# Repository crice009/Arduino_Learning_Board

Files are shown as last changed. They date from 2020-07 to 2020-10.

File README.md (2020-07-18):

# Arduino_Learning_Board
A set of resources to help with teaching and learning the skills of Arduino: coding, soldering, electronics, inputs and outputs. These include Arduino shield designs, BOM for ordering supplies, example sketches and a simple website for guiding structured learning/ play with these resources. 

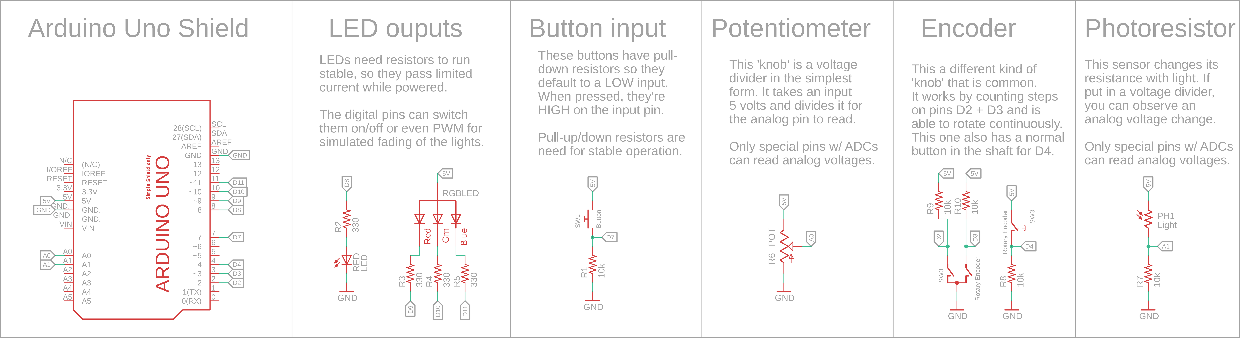
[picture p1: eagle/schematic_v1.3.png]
Schematic Image


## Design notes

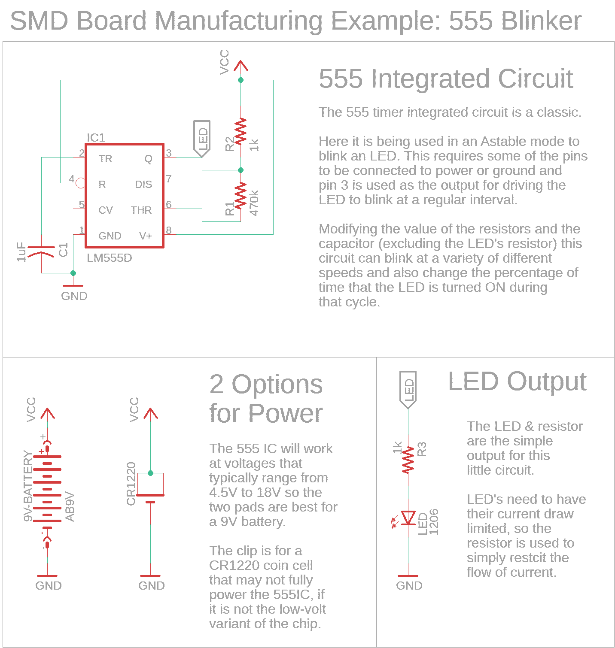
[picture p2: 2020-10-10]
eagle/schematic_555.png

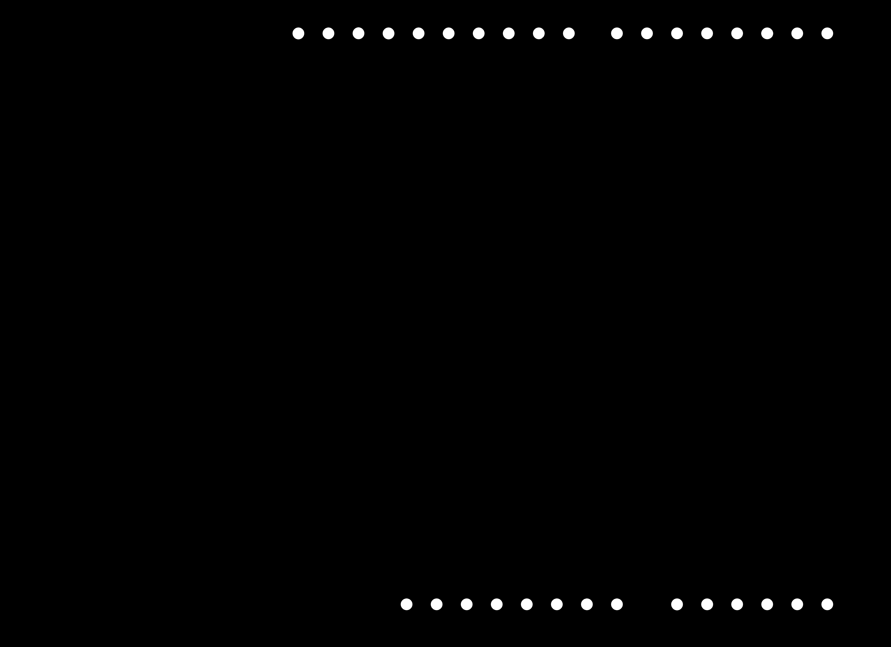
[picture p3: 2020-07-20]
eagle/single-sided_v2_holes.png

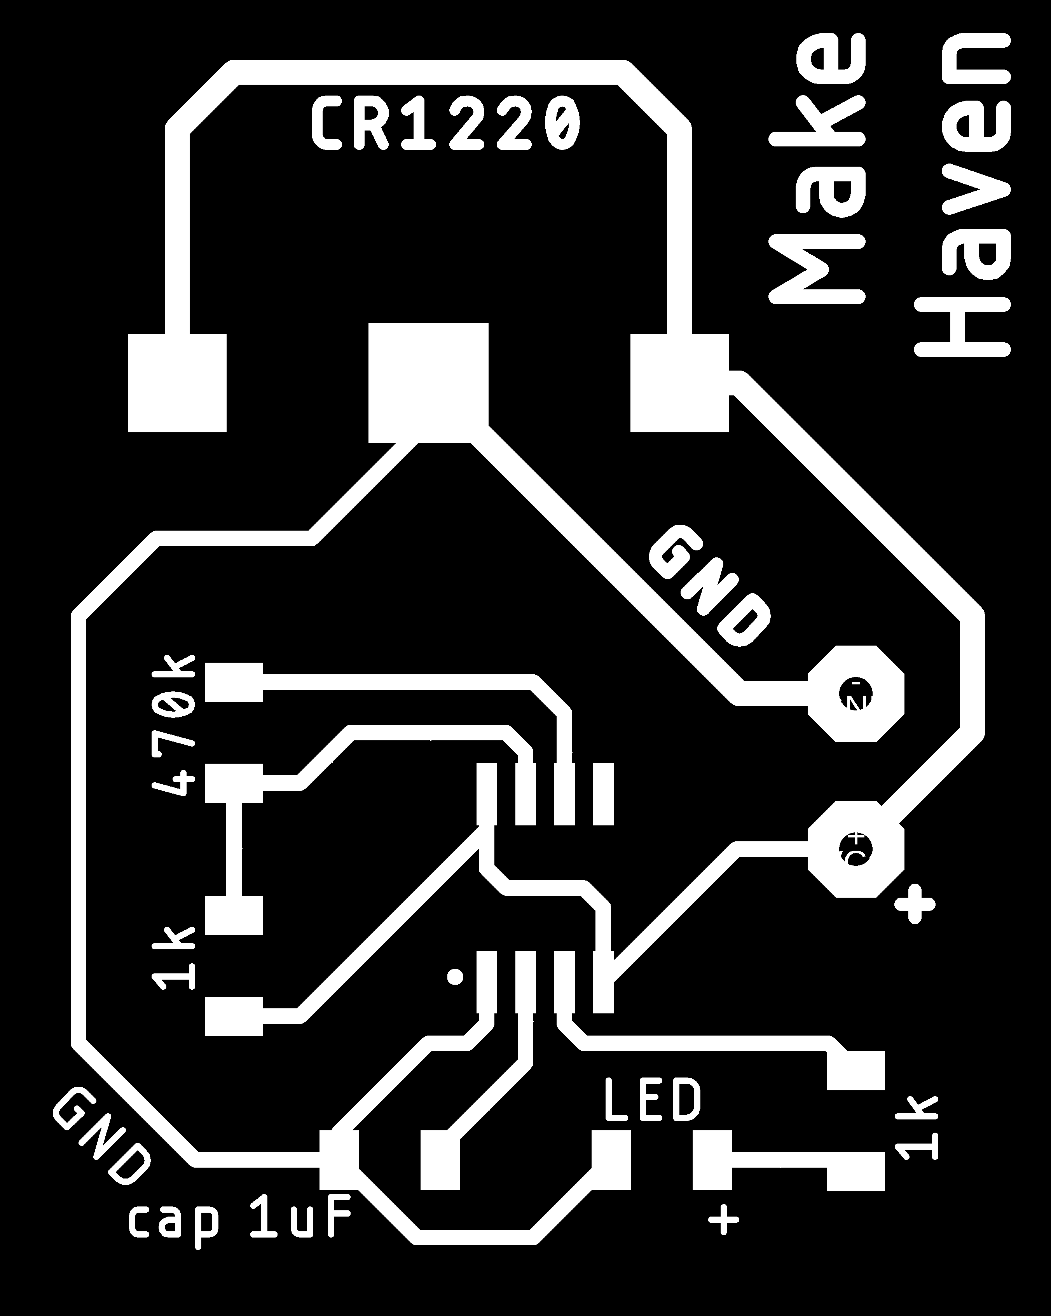
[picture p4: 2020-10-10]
eagle/555-blinker.png

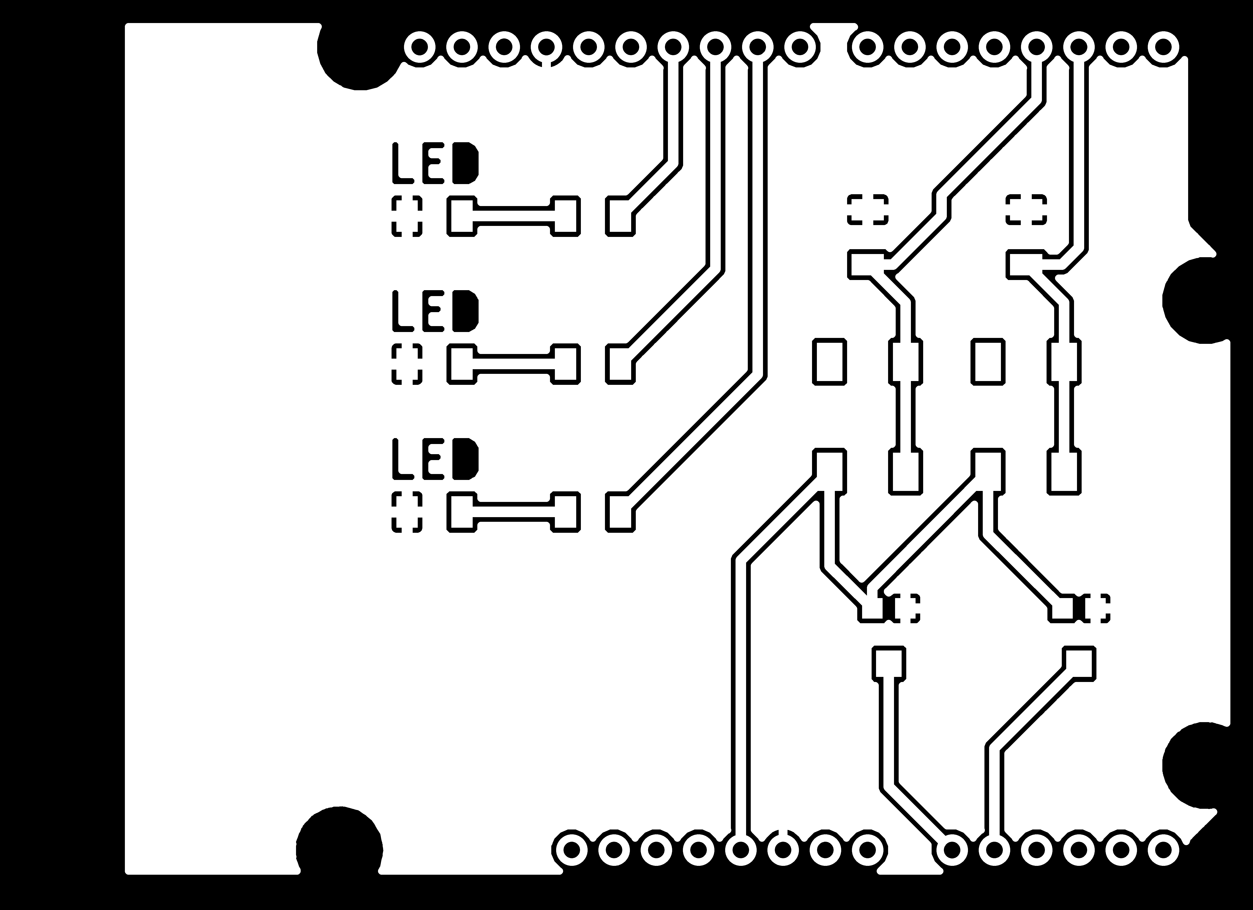
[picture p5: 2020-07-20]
eagle/single-sided_v2_traces_and_holes.png

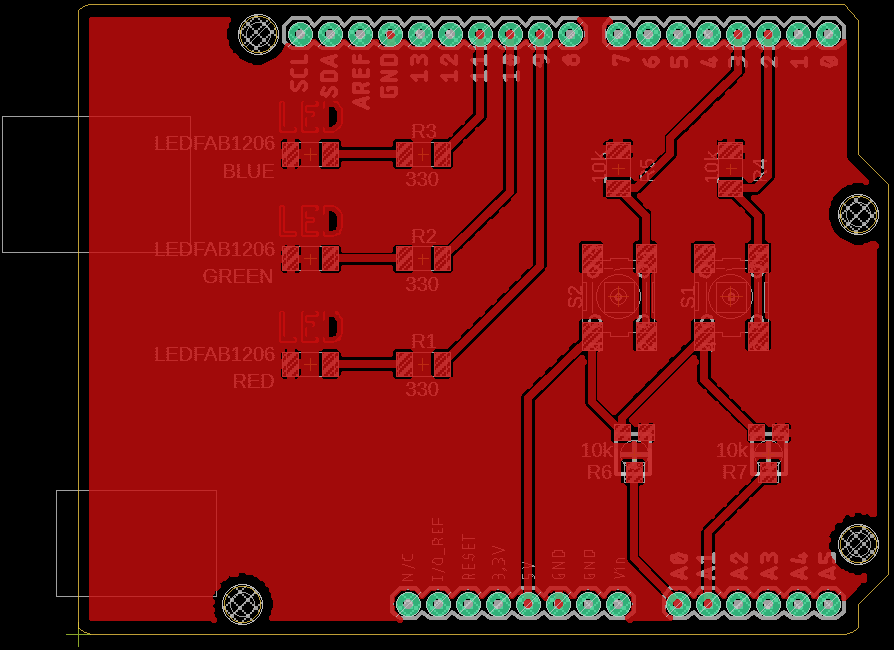
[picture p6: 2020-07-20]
eagle/single-sided_v2_color.png

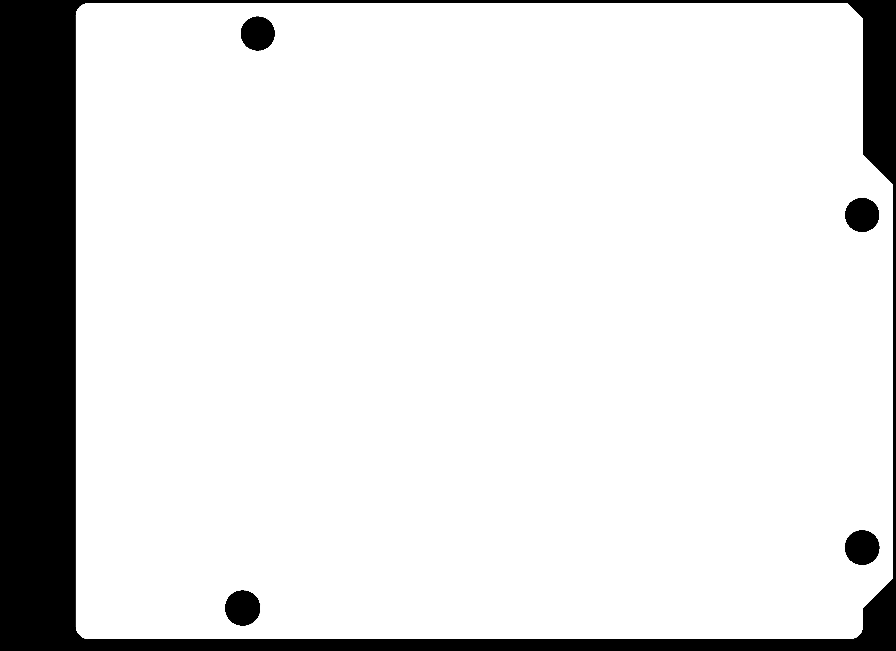
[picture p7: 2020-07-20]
eagle/single-sided_v2_cutout.png

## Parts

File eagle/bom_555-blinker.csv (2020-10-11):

Item | Quantity | individual cost | total cost | running total | Digikey
[8soic] 555-timer-IC (low-volts) | 1 | $0.88 | $0.88 | $0.88 | https://www.digikey.com/en/products/detail/texas-instruments/TLC555CDG4/1676492
[1206] 1 KOhm resistors | 2 | $0.10 | $0.20 | $1.08 | https://www.digikey.com/en/products/filter/chip-resistor-surface-mount/52
[1206] 470 KOhm resistors | 1 | $0.15 | $0.15 | $1.23 | https://www.digikey.com/en/products/filter/chip-resistor-surface-mount/52
[1206] LED | 1 | $0.26 | $0.26 | $1.49 | https://www.digikey.com/en/products/filter/led-indication-discrete/105?s=N4IgTCBcDaIIxgAwDYAEAbApgExAXQF8g
[1206] 1uF Capacitor | 1 | $0.14 | $0.14 | $1.63 | https://www.digikey.com/en/products/filter/ceramic-capacitors/60
CR1220 battery clip | 1 | $0.62 | $0.62 | $2.25 | https://www.digikey.com/en/products/detail/keystone-electronics/2894/9921790

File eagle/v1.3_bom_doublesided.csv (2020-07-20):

Item | Quantity | individual cost | total cost | running total | Digikey
male headers (6 pins long ea.) | 5 | $0.12 | $0.60 | $0.60 | https://www.digikey.com/product-detail/en/metz-connect-usa-inc/PR20206VBNN/1849-PR20206VBNN-ND/12342874
330 Ohm resistors | 4 | $0.10 | $0.40 | $1.00 | https://www.digikey.com/products/en/resistors/through-hole-resistors/53?k=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
10 KOhm resistors | 5 | $0.10 | $0.50 | $1.50 | https://www.digikey.com/products/en/resistors/through-hole-resistors/53?k=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
Single LED | 1 | $0.15 | $0.15 | $1.65 | https://www.digikey.com/products/en/optoelectronics/led-indication-discrete/105?k=5mm+led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
RGB LED | 1 | $1.01 | $1.01 | $2.66 | https://www.digikey.com/products/en/optoelectronics/led-indication-discrete/105?k=RGB+LED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
Button | 1 | $0.42 | $0.42 | $3.08 | https://www.digikey.com/products/en/switches/tactile-switches/197?k=EVQ-PE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
Encoder | 1 | $3.48 | $3.48 | $6.56 | https://www.digikey.com/product-detail/en/cui-devices/ACZ11BR1E-20FD1-20C/102-1768-ND/1923363
Potentiometer | 1 | $2.48 | $2.48 | $9.04 | https://www.digikey.com/products/en/potentiometers-variable-resistors/trimmer-potentiometers/80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
Phototcell | 1 | $0.89 | $0.89 | $9.93 | https://www.digikey.com/products/en/sensors-transducers/optical-sensors-photo-detectors-cds-cells/540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
board | 1 | $0.40 | $0.40 | $10.33 | Fab House

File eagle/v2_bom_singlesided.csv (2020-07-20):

Item | Quantity | individual cost | total cost | running total | Digikey
male headers (6 pins long ea.) | 5 | $0.12 | $0.60 | $0.60 | https://www.digikey.com/product-detail/en/metz-connect-usa-inc/PR20206VBNN/1849-PR20206VBNN-ND/12342874
330 Ohm SMD resistors | 3 | $0.10 | $0.30 | $0.90 | https://www.digikey.com/products/en/resistors/chip-resistor-surface-mount/52?k=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
10 KOhm SMD resistors | 2 | $0.10 | $0.20 | $1.10 | https://www.digikey.com/products/en/resistors/chip-resistor-surface-mount/52?k=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
Single SMD LED | 3 | $0.15 | $0.45 | $1.55 | https://www.digikey.com/products/en/optoelectronics/led-indication-discrete/105?k=1206+led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
button | 2 | $1.04 | $2.08 | $3.63 | https://www.digikey.com/product-detail/en/omron-electronics-inc-emc-div/B3SN-3112P/SW262CT-ND/60835
Potentiometer | 1 | $2.48 | $2.48 | $6.11 | https://www.digikey.com/products/en/potentiometers-variable-resistors/trimmer-potentiometers/80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
FR4 stock 6"x4" single sided | 0.5 | $7.34 | $3.67 | $9.78 | https://www.digikey.com/product-detail/en/mg-chemicals/506/473-1001-ND/559720

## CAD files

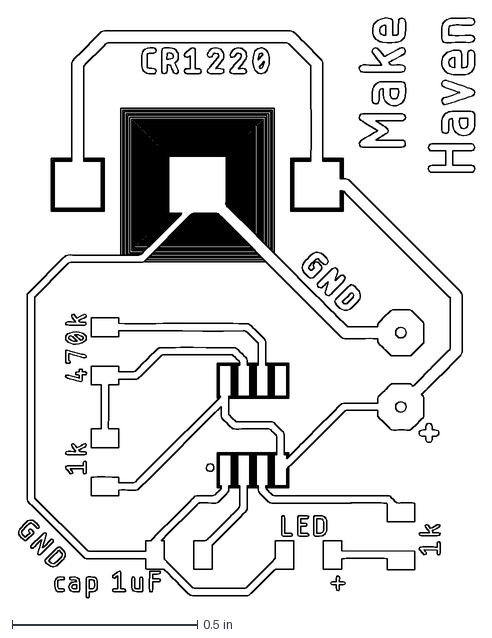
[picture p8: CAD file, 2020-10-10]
eagle/555-blinker.dxf
1.24 x 1.57 in

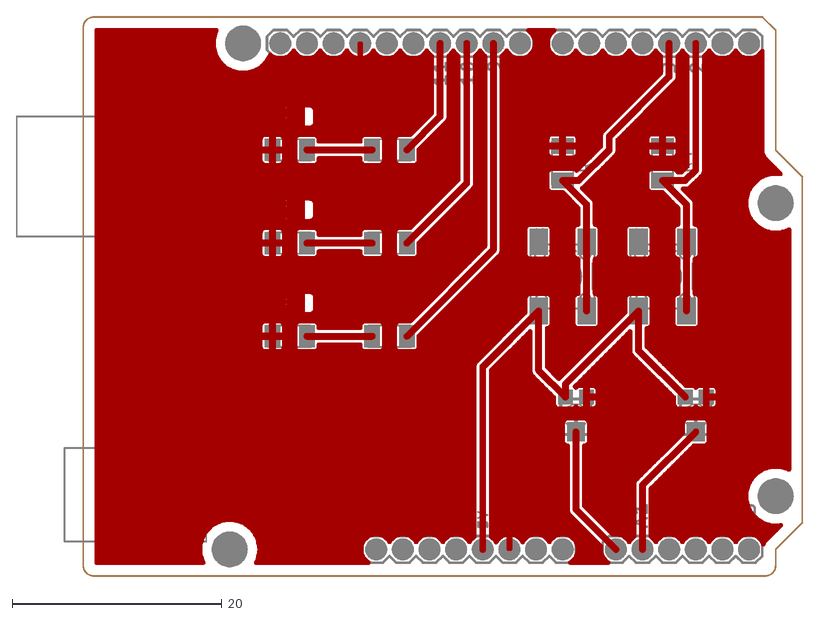
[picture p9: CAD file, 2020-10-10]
eagle/lb_single-sided_uno_v2.dxf
75.1 x 53.4

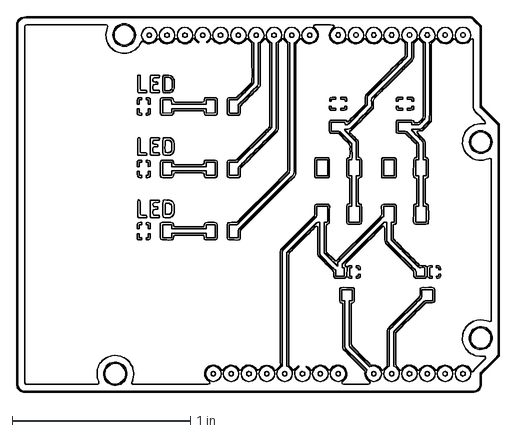
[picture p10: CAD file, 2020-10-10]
eagle/laserable-single-sided.dxf
2.71 x 2.11 in

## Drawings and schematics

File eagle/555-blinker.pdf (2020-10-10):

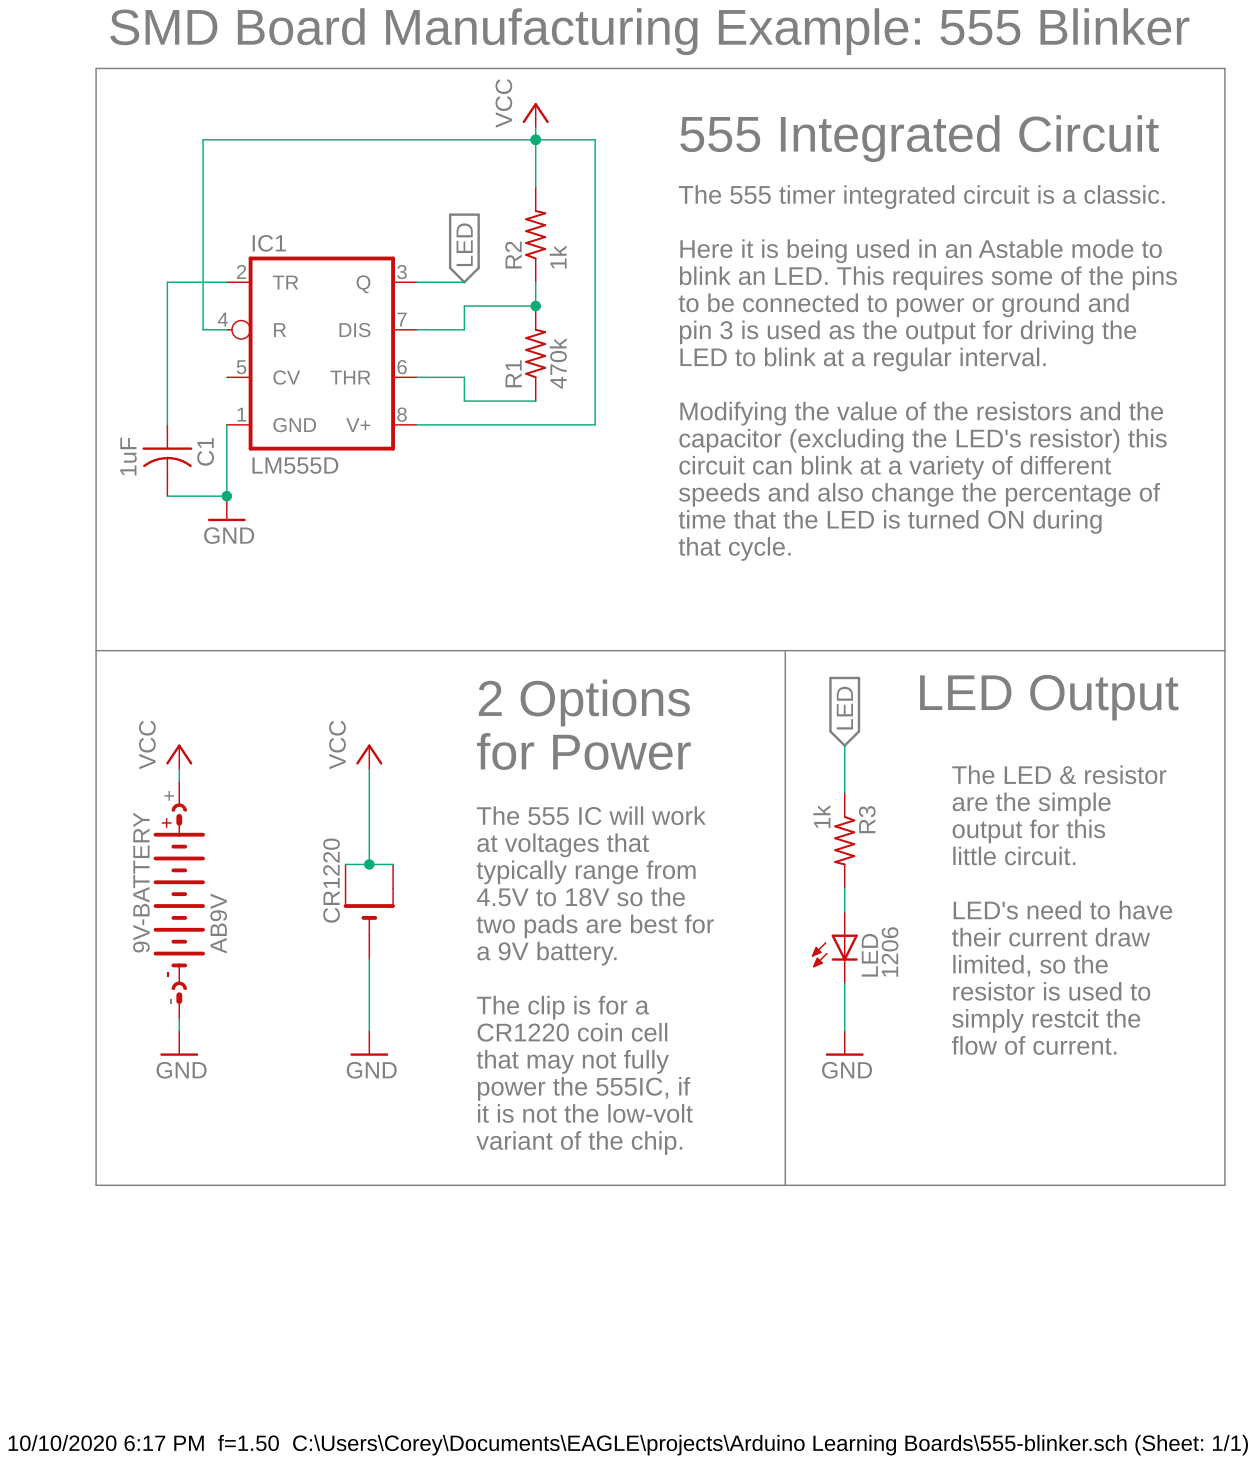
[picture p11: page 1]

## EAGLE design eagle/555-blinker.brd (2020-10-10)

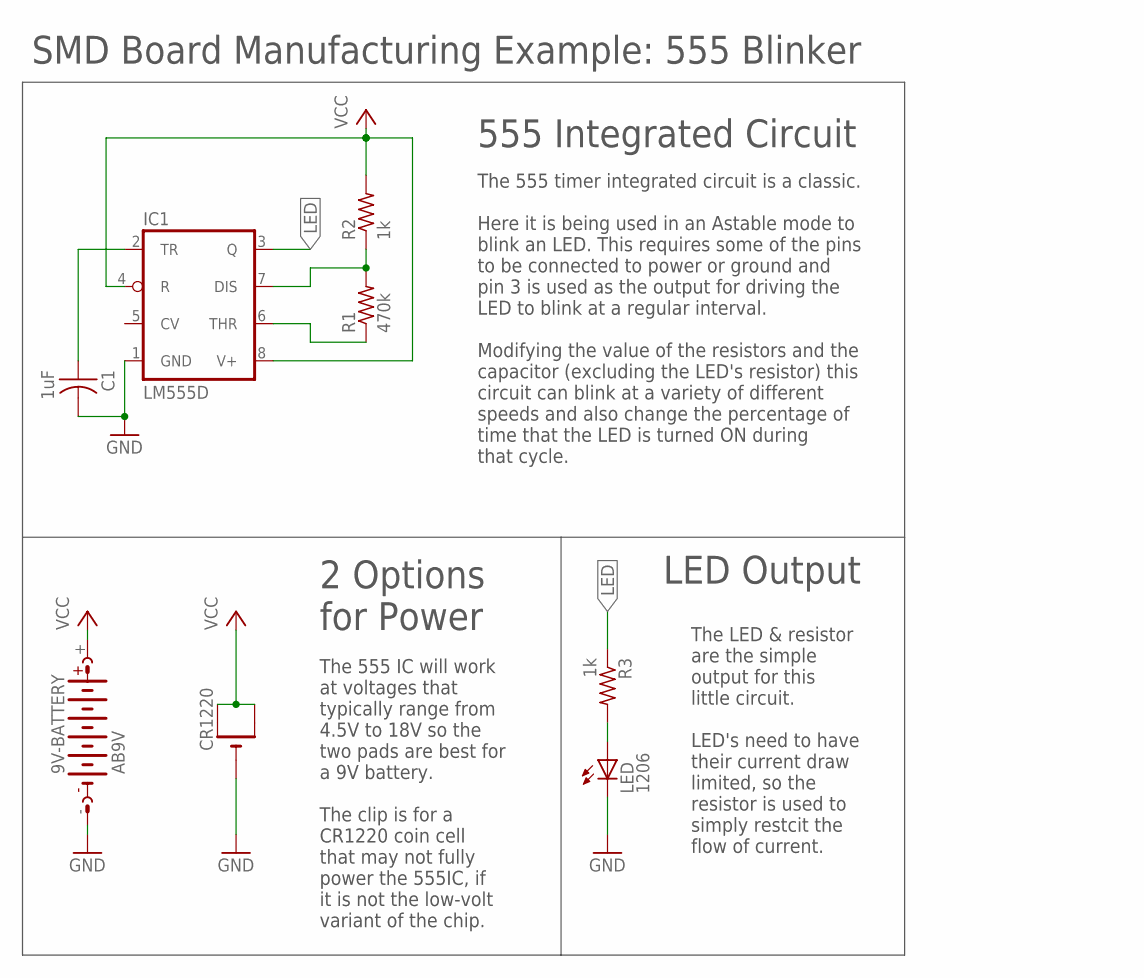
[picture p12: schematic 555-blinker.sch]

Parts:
9V-BATTERY: AB9V
C1: 1uF; C1206FAB
CR1220: CR1220SMT; CR1220-SMD
IC1: LM555D; SO08
LED: 1206; LED1206FAB
R1: 470k; R1206FAB
R2, R3: 1k; R1206FAB

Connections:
GND: 9V-BATTERY.-, C1.2, CR1220.-, IC1.1 (GND), LED.2 (C)
LED: IC1.3 (Q), R3.1
unnamed: IC1.7 (DIS), R1.2, R2.1
unnamed: IC1.6 (THR), R1.1
unnamed: C1.1, IC1.2 (TR)
unnamed: LED.1 (A), R3.2
VCC: 9V-BATTERY.+, CR1220.+$1 (+), CR1220.+$2 (+1), IC1.4 (R), IC1.8 (V+), R2.2

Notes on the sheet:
SMD Board Manufacturing Example: 555 Blinker
555 Integrated Circuit
2 Options for Power
LED Output
The 555 timer integrated circuit is a classic. Here it is being used in an Astable mode to blink an LED. This requires some of the pins to be connected to power or ground and pin 3 is used as the output for driving the LED to blink at a regular interval. Modifying the value of the resistors and the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
The 555 IC will work at voltages that typically range from 4.5V to 18V so the two pads are best for a 9V battery. The clip is for a CR1220 coin cell that may not fully power the 555IC, if it is not the low-volt variant of the chip.
The LED & resistor are the simple output for this little circuit. LED's need to have their current draw limited, so the resistor is used to simply restcit the flow of current.

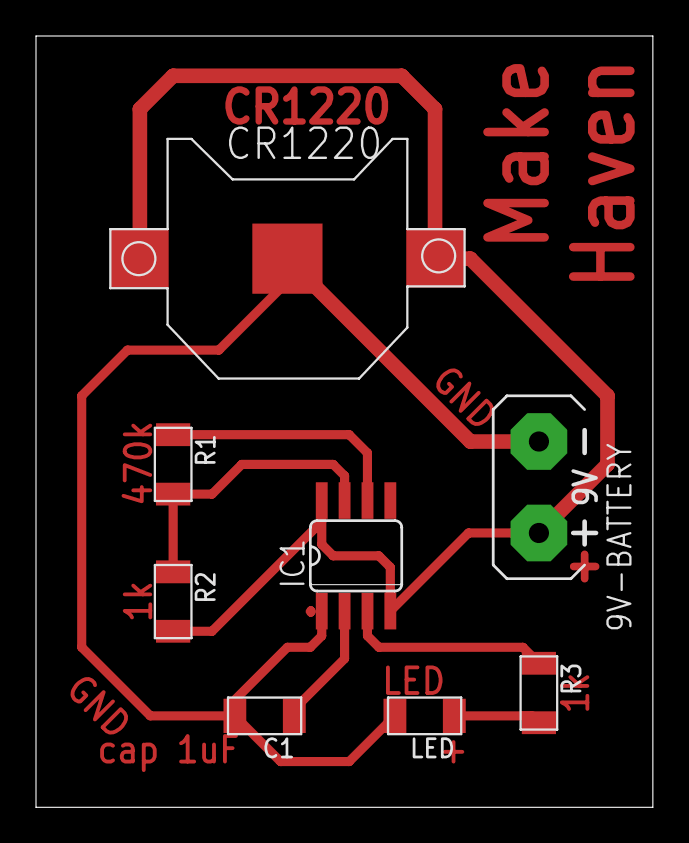
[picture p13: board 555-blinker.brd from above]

Board: 2 copper layers, 34.3 x 42.9 mm, 8 parts (0 on the bottom side), 7 nets.

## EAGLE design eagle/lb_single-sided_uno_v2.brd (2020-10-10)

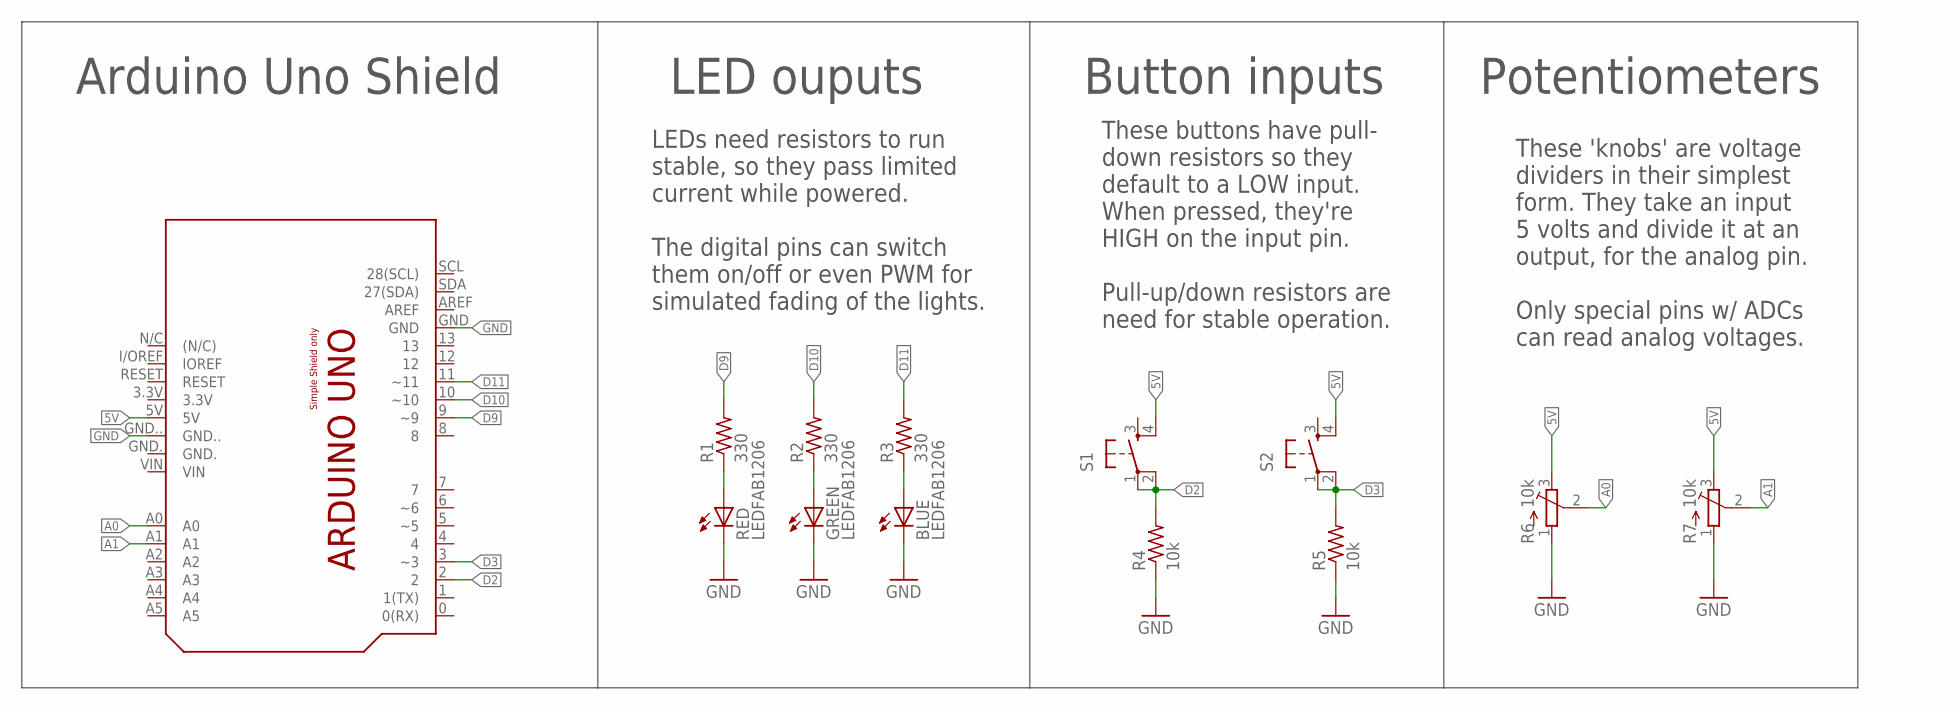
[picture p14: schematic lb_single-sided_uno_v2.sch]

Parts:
BLUE: LEDFAB1206; LED1206FAB
GREEN: LEDFAB1206; LED1206FAB
PCB1: ARDUINO_UNO_V2
R1, R2, R3: 330; R1206FAB
R4, R5: 10k; R1206FAB
R6, R7: 10k; TC33X
RED: LEDFAB1206; LED1206FAB
S1, S2: 6MM_SWITCH6MM_SWITCH; 6MM_SWITCH

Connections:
5V: PCB1.5V, R6.3 (E), R7.3 (E), S1.4 (S1), S2.4 (S1)
A0: PCB1.A0, R6.2 (S)
A1: PCB1.A1, R7.2 (S)
D2: PCB1.2, R4.2, S1.1, S1.2 (P1)
D3: PCB1.3 (~3), R5.2, S2.1, S2.2 (P1)
D9: PCB1.9 (~9), R1.2
D10: PCB1.10 (~10), R2.2
D11: PCB1.11 (~11), R3.2
GND: BLUE.2 (C), GREEN.2 (C), PCB1.GND, PCB1.GND.., R4.1, R5.1, R6.1 (A), R7.1 (A), RED.2 (C)
unnamed: R1.1, RED.1 (A)
unnamed: GREEN.1 (A), R2.1
unnamed: BLUE.1 (A), R3.1

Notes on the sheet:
Arduino Uno Shield
LED ouputs
Button inputs
LEDs need resistors to run stable, so they pass limited current while powered. The digital pins can switch them on/off or even PWM for simulated fading of the lights.
These buttons have pull- down resistors so they default to a LOW input. When pressed, they're HIGH on the input pin. Pull-up/down resistors are need for stable operation.
Potentiometers
These 'knobs' are voltage dividers in their simplest form. They take an input 5 volts and divide it at an output, for the analog pin. Only special pins w/ ADCs can read analog voltages.

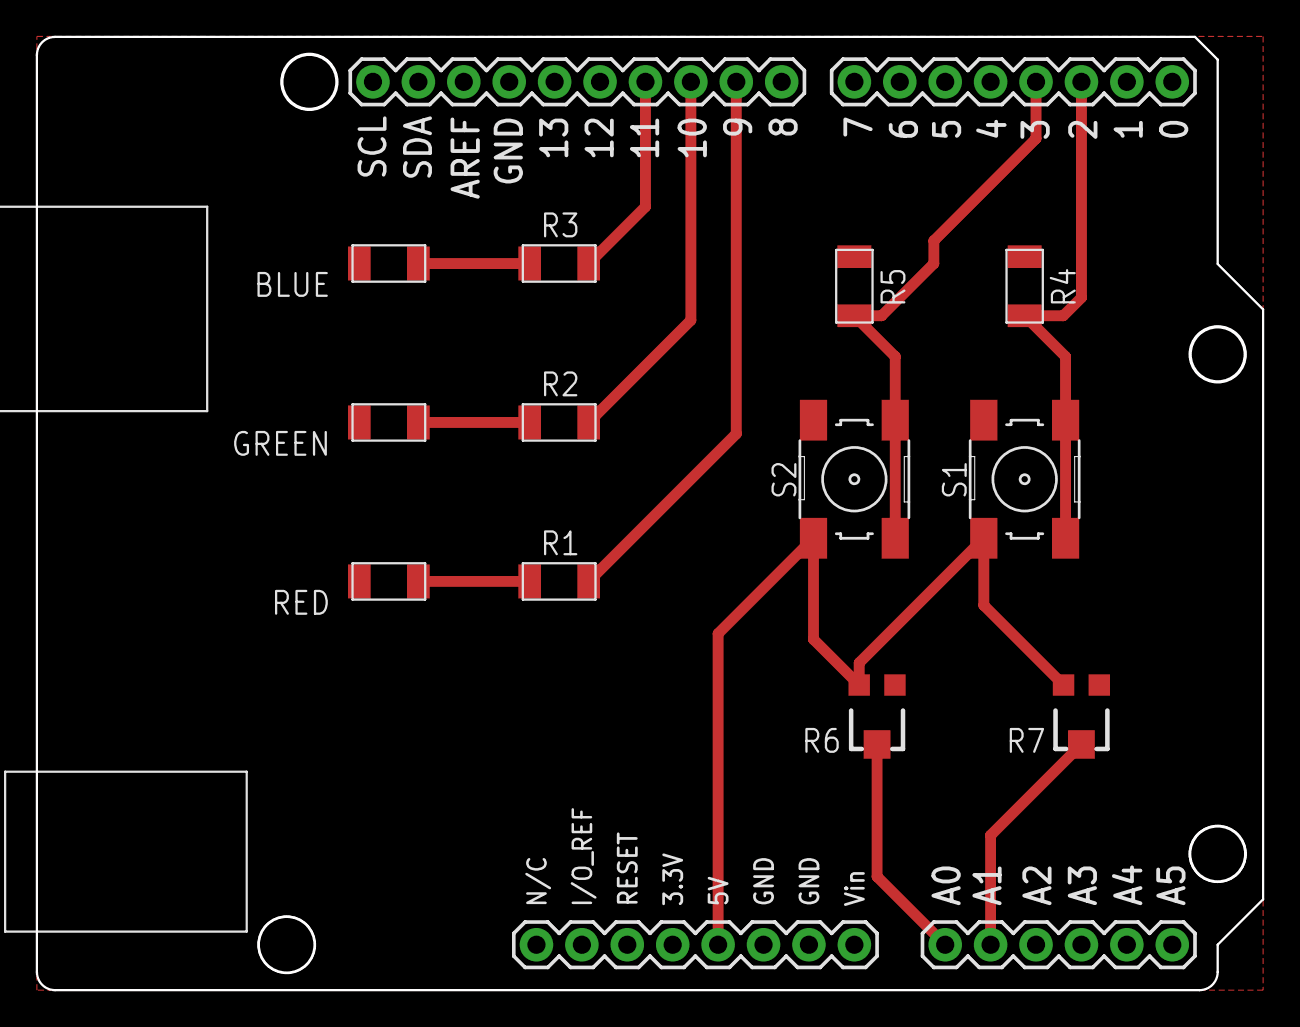
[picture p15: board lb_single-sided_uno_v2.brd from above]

Board: 2 copper layers, 68.6 x 53.3 mm, 13 parts (0 on the bottom side), 12 nets.

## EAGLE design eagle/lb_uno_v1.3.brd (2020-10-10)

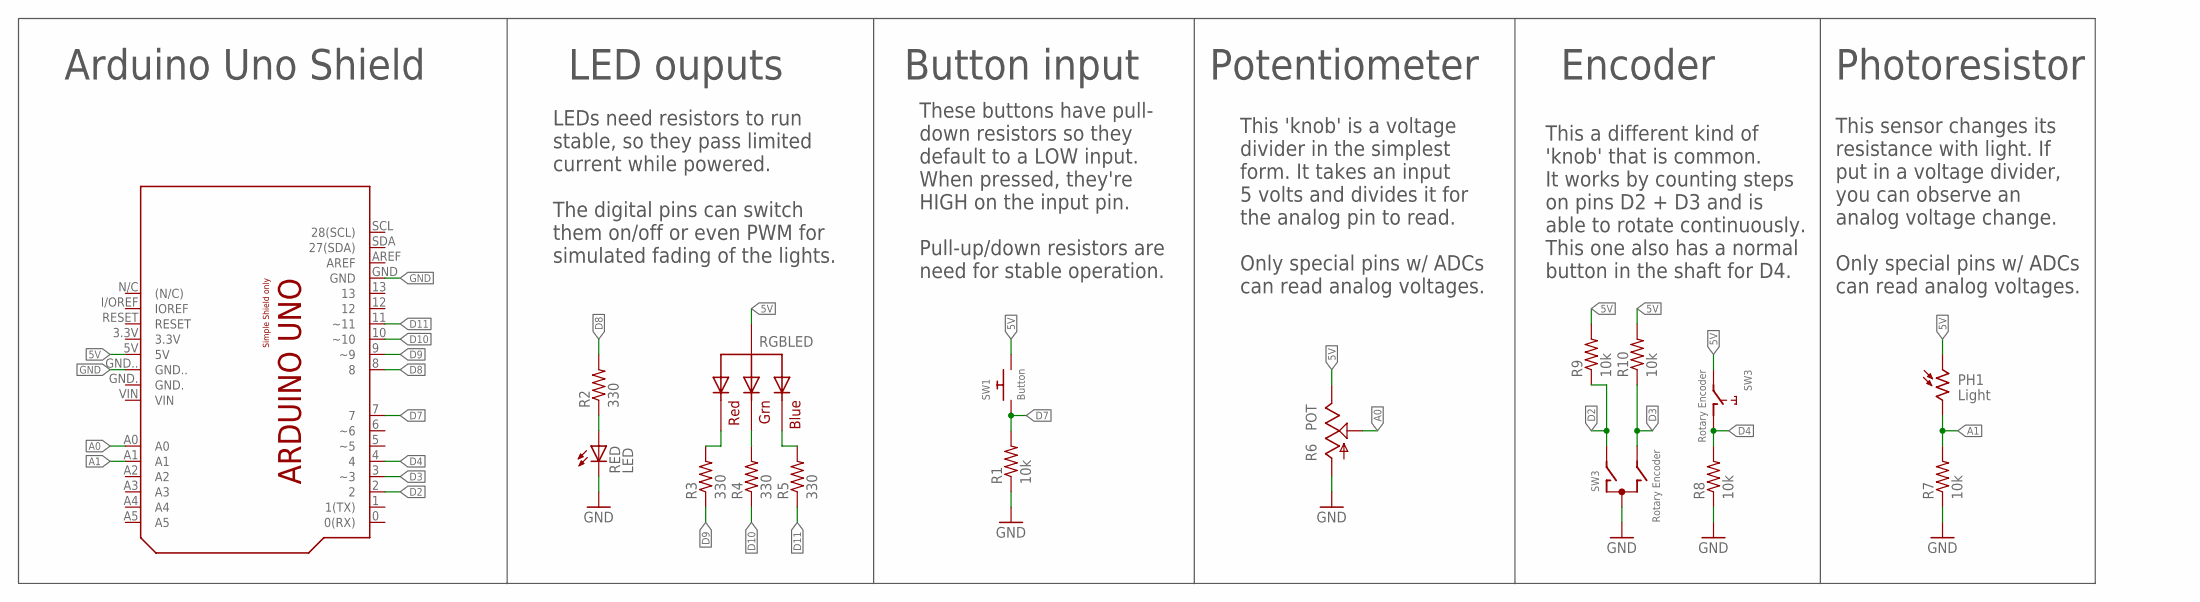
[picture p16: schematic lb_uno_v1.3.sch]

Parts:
PCB1: ARDUINO_UNO_V2
PH1: Light; T0-46-A10XX
R1, R7, R8, R9, R10: 10k; 0207/9
R2, R3, R4, R5: 330; 0207/9
R6: POT; B25P
RED: LED; 5MM
RGBLED: RGBLED; LED5MMRGB
SW1: Button; TACT_PANA-EVQ
SW3: Rotary Encoder; ALPS_EC12E_SW

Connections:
5V: PCB1.5V, PH1.1, R6.E, R9.2, R10.2, RGBLED.2 (VCC), SW1.P$2, SW3.E (2)
A0: PCB1.A0, R6.S
A1: PCB1.A1, PH1.2, R7.2
D2: PCB1.2, R9.1, SW3.A
D3: PCB1.3 (~3), R10.1, SW3.B
D4: PCB1.4, R8.2, SW3.D (1)
D7: PCB1.7, R1.2, SW1.P$1
D8: PCB1.8, R2.2
D9: PCB1.9 (~9), R3.1
D10: PCB1.10 (~10), R4.1
D11: PCB1.11 (~11), R5.1
GND: PCB1.GND, PCB1.GND.., R1.1, R6.A, R7.1, R8.1, RED.OUT (C), SW3.C
unnamed: R2.1, RED.IN (A)
unnamed: R3.2, RGBLED.1 (RED)
unnamed: R4.2, RGBLED.3 (GREEN)
unnamed: R5.2, RGBLED.4 (BLUE)

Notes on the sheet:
Arduino Uno Shield
LED ouputs
Button input
LEDs need resistors to run stable, so they pass limited current while powered. The digital pins can switch them on/off or even PWM for simulated fading of the lights.
These buttons have pull- down resistors so they default to a LOW input. When pressed, they're HIGH on the input pin. Pull-up/down resistors are need for stable operation.
Potentiometer
This 'knob' is a voltage divider in the simplest form. It takes an input 5 volts and divides it for the analog pin to read. Only special pins w/ ADCs can read analog voltages.
Encoder
This a different kind of 'knob' that is common. It works by counting steps on pins D2 + D3 and is able to rotate continuously. This one also has a normal button in the shaft for D4.
Photoresistor
This sensor changes its resistance with light. If put in a voltage divider, you can observe an analog voltage change. Only special pins w/ ADCs can read analog voltages.

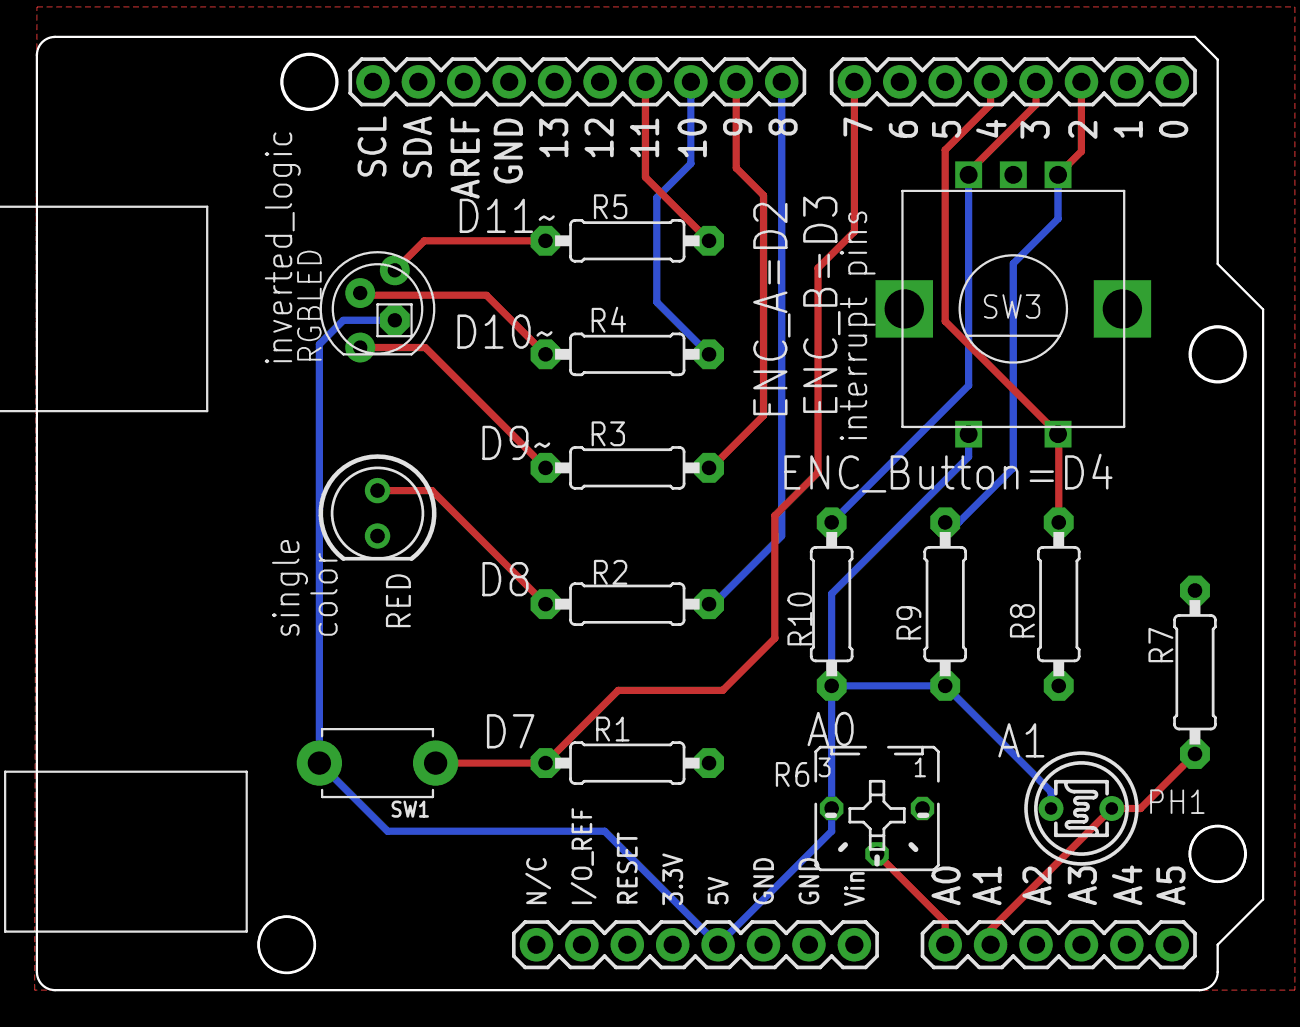
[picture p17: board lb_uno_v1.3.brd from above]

Board: 2 copper layers, 68.6 x 53.3 mm, 16 parts (0 on the bottom side), 16 nets.

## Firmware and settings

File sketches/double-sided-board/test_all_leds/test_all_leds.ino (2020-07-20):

/*
  Arrays

  Demonstrates the use of an array to hold pin numbers in order to iterate over
  the pins in a sequence. Lights multiple LEDs in sequence, then in reverse.

  Unlike the For Loop tutorial, where the pins have to be contiguous, here the
  pins can be in any random order.

  The circuit:
  - LEDs from pins 8 through 11 to ground

  created 2006
  by David A. Mellis
  modified 30 Aug 2011
  by Tom Igoe
  modified 2020
  by Corey Rice

  This example code is in the public domain.

  http://www.arduino.cc/en/Tutorial/Array
*/

int timer = 100;           // The higher the number, the slower the timing.
int ledPins[] = {
  8, 9, 10, 11
};       // an array of pin numbers to which LEDs are attached
int pinCount = 4;           // the number of pins (i.e. the length of the array)

void setup() {
  // the array elements are numbered from 0 to (pinCount - 1).
  // use a for loop to initialize each pin as an output:
  for (int thisPin = 0; thisPin < pinCount; thisPin++) {
    pinMode(ledPins[thisPin], OUTPUT);
  }
}

void loop() {
  // loop from the lowest pin to the highest:
  for (int thisPin = 0; thisPin < pinCount; thisPin++) {
    // turn the pin on:
    digitalWrite(ledPins[thisPin], HIGH);
    delay(timer);
    // turn the pin off:
    digitalWrite(ledPins[thisPin], LOW);

  }

  // loop from the highest pin to the lowest:
  for (int thisPin = pinCount - 1; thisPin >= 0; thisPin--) {
    // turn the pin on:
    digitalWrite(ledPins[thisPin], HIGH);
    delay(timer);
    // turn the pin off:
    digitalWrite(ledPins[thisPin], LOW);
  }
}

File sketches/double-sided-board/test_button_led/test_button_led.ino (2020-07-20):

/*
  Button

  Turns on and off a light emitting diode(LED) connected to digital pin 13,
  when pressing a pushbutton attached to pin 2.

  The circuit:
  - LED attached from pin 13 to ground
  - pushbutton attached to pin 2 from +5V
  - 10K resistor attached to pin 2 from ground

  - Note: on most Arduinos there is already an LED on the board
    attached to pin 13.

  Turns on and off a light emitting diode(LED) connected to digital pin 8,
  when pressing a pushbutton attached to pin 7.

  The circuit:
  - LED attached from pin 8 to ground
  - pushbutton attached to pin 7 from +5V
  - 10K resistor attached to pin 7 from ground

  created 2005
  by DojoDave <http://www.0j0.org>
  modified 30 Aug 2011
  by Tom Igoe
  modified july 2020
  by Corey Rice

  This example code is in the public domain.

  http://www.arduino.cc/en/Tutorial/Button
*/

// constants won't change. They're used here to set pin numbers:
const int buttonPin1 = 7;     // the number of the pushbutton pin
const int ledPin =  8;      // the number of the LED pin

// variables will change:
int buttonState = 0;         // variable for reading the pushbutton status

void setup() {
  // initialize the LED pin as an output:
  pinMode(ledPin, OUTPUT);
  // initialize the pushbutton pin as an input:
  pinMode(buttonPin, INPUT);
}

void loop() {
  // read the state of the pushbutton value:
  buttonState = digitalRead(buttonPin);

  // check if the pushbutton is pressed. If it is, the buttonState is HIGH:
  if (buttonState == HIGH) {
    // turn LED on:
    digitalWrite(ledPin, HIGH);
  } else {
    // turn LED off:
    digitalWrite(ledPin, LOW);
  }
}

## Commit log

2020-07-18 first reaal commit
    [lb_uno_v1.3.brd, lb_uno_v1.3.sch]
2020-07-19 needed to change the single sided board to SMD parts so they are solderable & provide practice
    [lb_single-sided_uno_v2.brd, lb_single-sided_uno_v2.sch]
2020-07-20 updated board designs and docs
    [lb_single-sided_uno_v2.brd, lb_single-sided_uno_v2.sch, lb_uno_v1.3.brd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]
2020-07-20 added bill of materials
    [v1.3_bom_doublesided.csv, v2_bom_singlesided.csv]
2020-07-20 formatted bill of materials for preentation on the web
    [v1.3_bom_doublesided.csv, v2_bom_singlesided.csv]
2020-07-20 added arduino sketch examples
2020-07-20 updated commentary in arduino sketches
2020-10-10 added 555 circuit
    [555-blinker.brd, 555-blinker.dxf, 555-blinker.sch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]
2020-10-11 added BOM for 555 circuit
    [bom_555-blinker.csv]
2020-10-11 updated gerber files link
